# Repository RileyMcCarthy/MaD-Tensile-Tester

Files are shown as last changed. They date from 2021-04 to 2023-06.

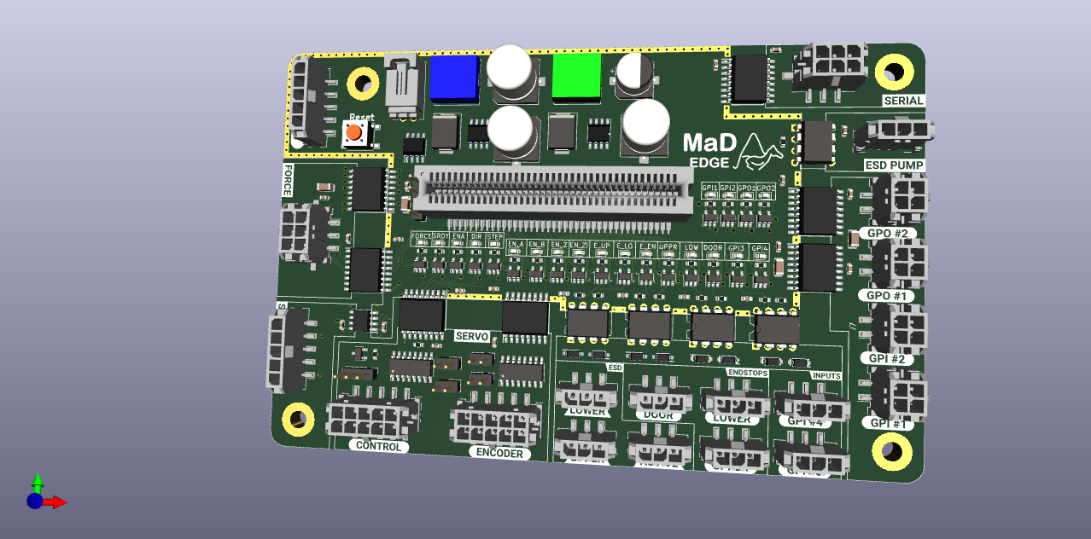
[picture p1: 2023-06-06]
Docs/MaD_Edge_2.png

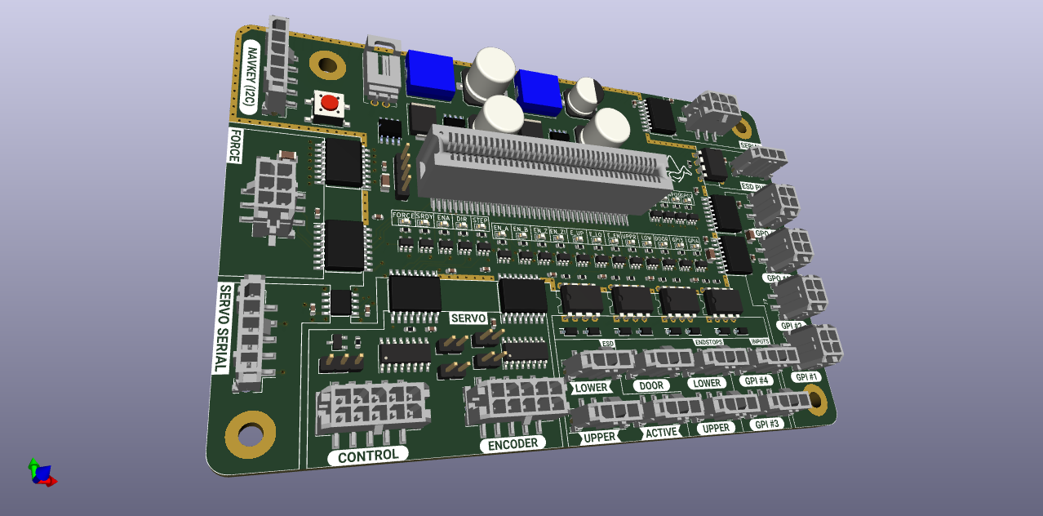
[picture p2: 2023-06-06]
Docs/MaD_Edge_1.png

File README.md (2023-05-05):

# Low Modulus High Speed Tensile Testing Machine

## Purpose

Function as a relatively low cost (< $4,000), portable, spray resistant, user modifiable, open-source uniaxial tensile testing machine for low modulus elastomeric and biologic materials. 

## Physical Specifications

- Strain Rate 0 – 2 m/s

- Force Measurement Range 1 – 10 N

- Gauge Length 10 – 150 mm

- Strain Length 0 – 500 mm

- Data generation rate 1000 sps

## Power Up Sequence

1. Turning on the mains inlet power switch will power the motion control electronics including the “inboard” power on the tensile board 

2. Depressing the on button of the momentary on-off button pair will apply DC power to the machine status switches and ESD chain circuit. 

3. Release of the ESD switch which will apply AC power to the servo controller. 

4. When machine operational and safety criteria are met, motion is affected through operator actuation of the reset function with a control panel and touch screen. 

5. The power down sequence is the reverse of the power up sequence with the off button of the momentary on-off button pair being pressed to remove DC power.

## Operation

The machine state machine operates in three main states with corresponding parameters; 

1. Self Check
- Charge Pump Activated (**ON**/OFF)
2. Machine Check
- Switched Power (**ON**/OFF)
- ESD Travel Limits (**OK**/UPPER FAULT/LOWER FAULT)
- ESD Switch (**ON**/OFF)
- Servo Ready (**YES**/NO)
- Servo Communicating (**YES**/NO)
- Force Gauge Ready (**YES**/NO)
3. Motion
- Mode (Manual or Test)
- Status (DISABLED, ENABLED, SAMPLE LIMIT, MACHINE LIMIT, FAULT)
- Condition (Length, Force, Tension, Compression, Upper Limit, Lower Limit, Door, Stopped, Moving)

## Manual Mode

Manual Operation Mode controls the motor based on user input. The user can selected from the following functions: Off, Incremental Jog, Continuous Jog, Move to Position, Handwheel Jog, Move to Home Position, Set or Move to a Gauge Length, Set or Move to a Force Level and Hold. 

## Test Mode 
Test Mode controls the motor automatically using the functions: Load, Run, Stop Test (Stop Tst) and Hold/Resume.  Motion Profiles are executed by the Run Function. 

** Documentation is a WIP **

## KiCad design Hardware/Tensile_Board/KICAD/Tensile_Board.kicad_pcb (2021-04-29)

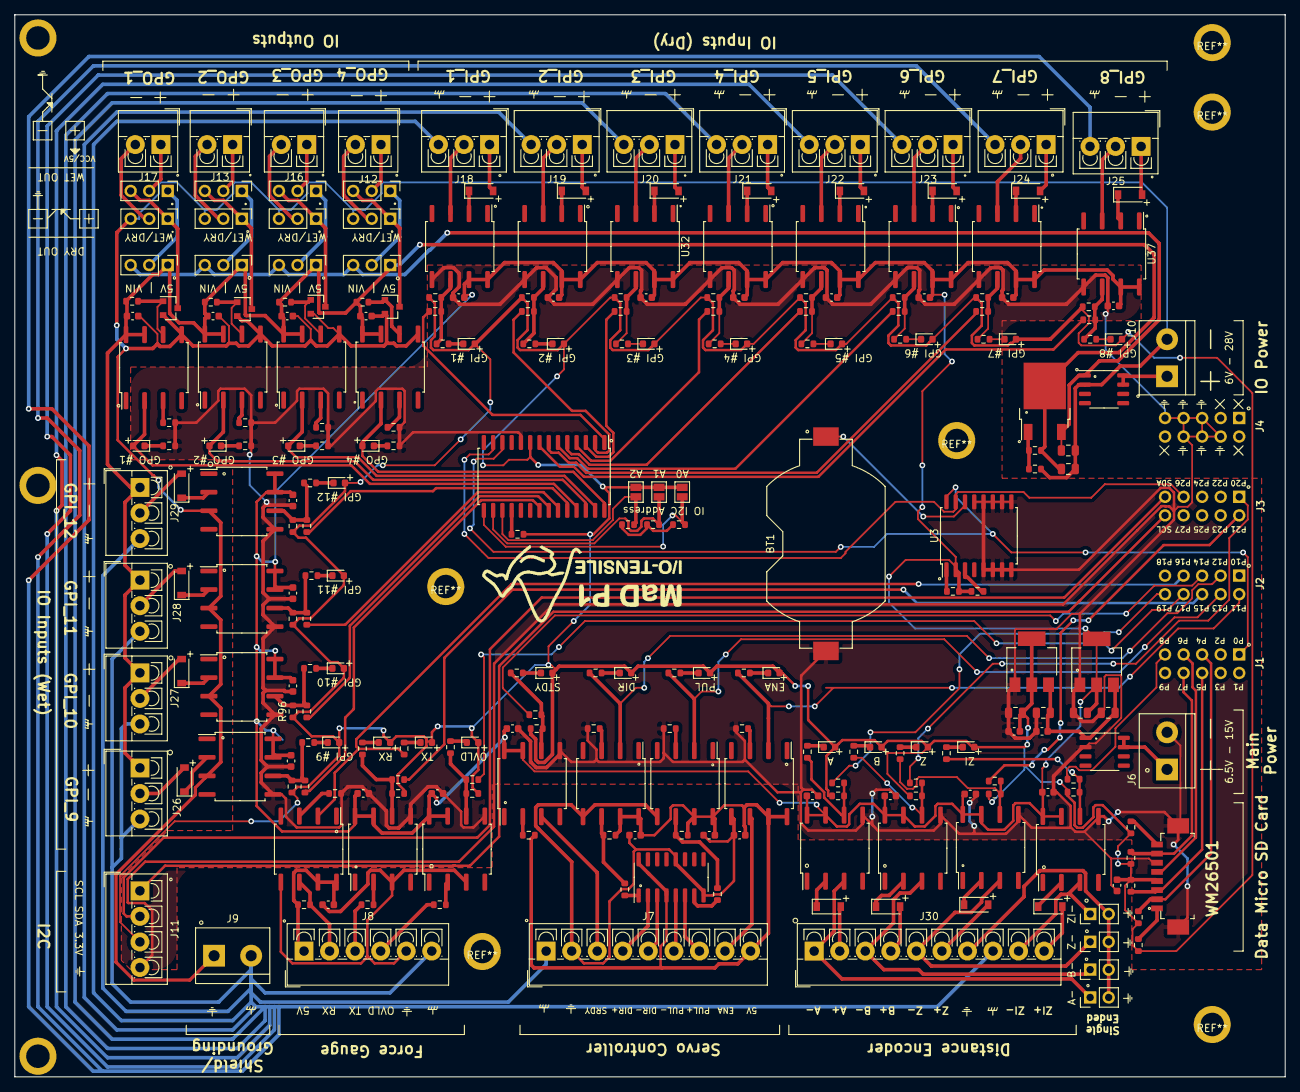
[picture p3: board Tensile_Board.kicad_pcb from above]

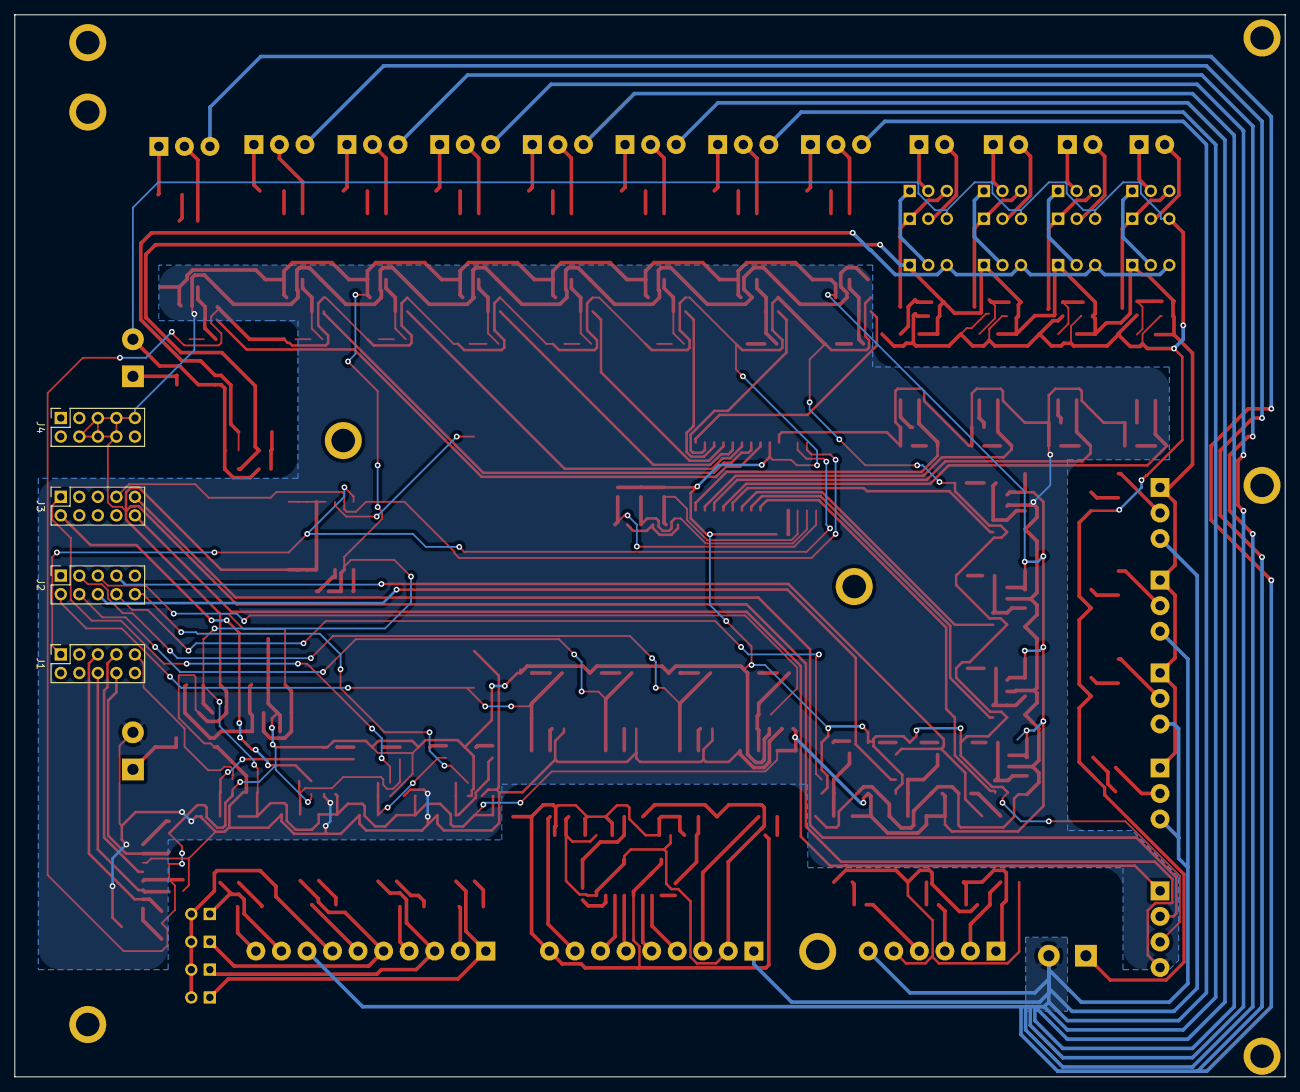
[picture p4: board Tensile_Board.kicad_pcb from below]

Board: 2 copper layers, 174.0 x 145.5 mm, 268 parts (4 on the bottom side), 195 nets.

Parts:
BT1: CR2032; BatteryHolder_Keystone_1058_1x2032
C1, C8, C9, C12, C13, C14, C15, C16, C17, C18, C19, C20, C23, C24, C25, C26, C27, C28, C29, C30, C31, C32, C33, C34, C35, C36, C37, C38: 0.1uF; C_0603_1608Metric
C2, C3: 10uF; C_0805_2012Metric
C4, C6: 4.7uF; C_0805_2012Metric
C5, C7: 1uF; C_0603_1608Metric
C21: 0.1uF; C_0805_2012Metric
C22: 1uF; C_0805_2012Metric
D1, D2, D4, D5, D6, D7, D8, D9, D10, D11, D12, D13, D14, D15, D16, D17, D18, D19, D20, D21, D22, D23, D24, D25, D26, D27: BLUE; LED_0603_1608Metric
D3: LED; LED_0603_1608Metric
DISP_HOLE_1, DISP_HOLE_2, DISP_HOLE_3: Hole_5.08
J1, J2, J3, J4: Conn_02x05_Odd_Even; PinSocket_2x05_P2.54mm_Vertical
J5: Micro_SD_Card; WM26501
J6: Main_Power; TerminalBlock_bornier-2_P5.08mm
J7: Screw_Terminal_01x09; TerminalBlock_4Ucon_1x09_P3.50mm_Vertical
J8: Screw_Terminal_01x06; TerminalBlock_4Ucon_1x06_P3.50mm_Vertical
J9: Grounding; TerminalBlock_bornier-2_P5.08mm
J10: IO_Power; TerminalBlock_bornier-2_P5.08mm
J11: Screw_Terminal_01x04; TerminalBlock_4Ucon_1x04_P3.50mm_Vertical
J12, J13, J16, J17: Screw_Terminal_01x02; TerminalBlock_4Ucon_1x02_P3.50mm_Vertical
J18, J19, J20, J21, J22, J23, J24, J25, J26, J27, J28, J29: Screw_Terminal_01x03; TerminalBlock_4Ucon_1x03_P3.50mm_Vertical
J30: Screw_Terminal_01x10; TerminalBlock_4Ucon_1x10_P3.50mm_Vertical
JP1: A2; SolderJumper-2_P1.3mm_Open_Pad1.0x1.5mm
JP2: A1; SolderJumper-2_P1.3mm_Open_Pad1.0x1.5mm
JP3: A0; SolderJumper-2_P1.3mm_Open_Pad1.0x1.5mm
JP4, JP5, JP6, JP7: Jumper_2_Open; PinHeader_1x02_P2.54mm_Vertical
JP10, JP11, JP12, JP13, JP15, JP16, JP18, JP19, JP21, JP22, JP24, JP25: Jumper_3_Open; PinHeader_1x03_P2.54mm_Vertical
LOGO: LOGO_1
Q3, Q4, Q5, Q6, Q7, Q8, Q9, Q10, Q11, Q12, Q13, Q14, Q15, Q16, Q17, Q18: NSI50010Y; D_SOD-123
R1, R2, R3, R4, R5: 100K; R_0603_1608Metric
R6, R7: 4.7K; R_0603_1608Metric
R8, R9, R17, R24, R25, R26, R27, R28, R29, R38, R39, R40, R41, R56, R57, R58, R59, R60, R61, R68, R69, R70, R71, R72, R73: 10K; R_0603_1608Metric
R10, R11, R18: 360R; R_0603_1608Metric
R12, R19, R20: 470R; R_0603_1608Metric
R13, R14, R15, R21, R42, R43, R44, R45: 270R; R_0603_1608Metric
R16, R32, R33, R34, R35: 620R; R_0603_1608Metric
R22, R23: 330R; R_0603_1608Metric
R30, R31, R36, R37, R50, R51, R52, R53, R54, R55, R62, R63, R64, R65, R66, R67, R77, R78, R79, R80, R81, R82, R83, R84, R85, R86: 100R; R_0603_1608Metric
R46, R47, R48, R49, R87, R88, R89, R90, R91, R92, R93, R94, R95, R96, R97, R98: 1K; R_0603_1608Metric
R74: 680R; R_0603_1608Metric
R75: 220R; R_0603_1608Metric
R76: 33R; R_0603_1608Metric
U1: AMS1117-5.0; SOT-223-3_TabPin2
U2: AMS1117-3.3; SOT-223-3_TabPin2
U3: DS3231M; SOIC-16W_7.5x10.3mm_P1.27mm
U4: AM26LS31CDR; SOIC-16_3.9x9.9mm_P1.27mm
U5, U6, U7, U8, U9, U10, U11, U15, U16, U17, U18, U22, U23, U24, U25, U30, U31, U32, U33, U34, U35, U36, U37, U38, U39, U40, U41: 6N137; SOP-8_6.62x9.15mm_P2.54mm
U12: MCP23017_SO; SOIC-28W_7.5x17.9mm_P1.27mm
U13, U20: APM4953; SOP-8_3.9x4.9mm_P1.27mm
U21: LM317_TO-252; TO-252-2
U26, U27, U28, U29: NUD3124; SOT-23

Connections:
5V_IO: C22.1, C23.1, C24.1, C25.1, C26.1, J26.1, J27.1, J28.1, J29.1, JP10.1, JP11.1, JP12.1, JP13.1, R46.1, R47.1, R48.1, R49.1, R75.1, U21.2, U22.7, U22.8, U23.7, U23.8, U24.7, U24.8, U25.7, U25.8
+3V3_TS: C1.1, C6.1, C7.1, D1.2, D2.2, D7.2, D8.2, D9.2, D10.2, D11.2, D12.2, D13.2, D14.2, D15.2, D16.2, D17.2, D18.2, D19.2, D20.2, D21.2, D22.2, D23.2, D24.2, D25.2, D26.2, D27.2, J5.4, J11.3, JP1.1, JP2.1, JP3.1, R1.1, R2.1, R3.1, R4.1, R5.1, R16.1, R22.1, R23.1, R28.1, R32.1, R33.1, R34.1, R35.1, R87.1, R88.1, R89.1, R90.1, R91.1, R92.1, R93.1, R94.1, R95.1, R96.1, R97.1, R98.1, U2.2, U12.9
+5V_FG: C18.1, J8.1, R18.1, U9.7, U9.8
+5V_SC: C8.1, C9.1, C16.1, J7.9, R10.1, R11.1, R12.1, U4.4, U4.16, U5.7, U5.8, U6.7, U6.8, U7.7, U7.8
+5V_TS: C3.1, C12.1, C13.1, C14.1, C15.1, C17.1, C19.1, C20.1, C27.1, C28.1, C29.1, C30.1, C31.1, C32.1, C33.1, C34.1, C35.1, C36.1, C37.1, C38.1, R6.1, R7.1, U1.2, U3.2, U8.7, U8.8, U10.7, U10.8, U11.7, U11.8, U15.7, U15.8, U16.7, U16.8, U17.7, U17.8, U18.7, U18.8, U30.7, U30.8, U31.7, U31.8, U32.7, U32.8, U33.7, U33.8, U34.7, U34.8, U35.7, U35.8, U36.7, U36.8, U37.7, U37.8, U38.7, U38.8, U39.7, U39.8, U40.7, U40.8, U41.7, U41.8
DIR: R8.1, U4.1
DIR+: J7.4, U4.2
DIR-: J7.5, U4.3
ENA: J7.8, U6.6
FG_OVLD: J8.4, R19.1
FG_RX: J8.2, R18.2, U9.6
FG_TX: J8.3, R20.1
GND: R26.2, R27.2, R29.2
GND_ENC: J30.7, JP4.2, JP5.2, JP6.2, JP7.2
GND_FG: C18.2, J8.5, U9.5, U10.3, U11.3
GND_IO: C21.2, C22.2, C23.2, C24.2, C25.2, C26.2, J9.1, J10.2, JP16.3, JP19.3, JP22.3, JP25.3, R74.2, U13.2, U22.5, U23.5, U24.5, U25.5, U26.2, U27.2, U28.2, U29.2, U38.3, U39.3, U40.3, U41.3
GND_SC: C8.2, C9.2, C16.2, J7.2, U4.8, U4.12, U5.5, U6.5, U7.5
GND_TSD: BT1.2, C1.2, C2.2, C3.2, C4.2, C5.2, C6.2, C7.2, C12.2, C13.2, C14.2, C15.2, C17.2, C19.2, C20.2, C27.2, C28.2, C29.2, C30.2, C31.2, C32.2, C33.2, C34.2, C35.2, C36.2, C37.2, C38.2, J4.4, J4.5, J4.6, J4.7, J4.8, J4.9, J5.6, J5.9, J6.2, J11.4, R13.2, R14.2, R15.2, R21.2, R42.2, R43.2, R44.2, R45.2, R76.2, R77.2, R78.2, R79.2, U1.1, U2.1, U3.5, U3.6, U3.7, U3.8, U3.9, U3.10, U3.11, U3.12, U3.13, U8.5, U10.5, U11.5, U12.10, U15.5, U16.5, U17.5, U18.5, U20.2, U30.5, U31.5, U32.5, U33.5, U34.5, U35.5, U36.5, U37.5, U38.5, U39.5, U40.5, U41.5
GPA0: R70.1, U12.21
GPA1: R71.1, U12.22
GPA2: R72.1, U12.23
GPA3: R73.1, U12.24
GPA4: D6.2, U12.25, U25.2
GPA5: D4.2, U12.26, U23.2
GPA6: D5.2, U12.27, U24.2
GPA7: D3.2, U12.28, U22.2
GPB0: R56.1, U12.1
GPB1: R57.1, U12.2
GPB2: R58.1, U12.3
GPB3: R59.1, U12.4
GPB4: R60.1, U12.5
GPB5: R61.1, U12.6
GPB6: R68.1, U12.7
GPB7: R69.1, U12.8
GPI_1+: J18.1, Q7.2
GPI_1-: J18.2, U30.3
GPI_2+: J19.1, Q8.2
GPI_2-: J19.2, U31.3
GPI_3+: J20.1, Q9.2
GPI_3-: J20.2, U32.3
GPI_4+: J21.1, Q10.2
GPI_4-: J21.2, U33.3
GPI_5+: J22.1, Q11.2
GPI_5-: J22.2, U34.3
GPI_6+: J23.1, Q12.2
GPI_6-: J23.2, U35.3
GPI_7+: J24.1, Q13.2
GPI_7-: J24.2, U36.3
GPI_8+: J25.1, Q14.2
GPI_8-: J25.2, U37.3
GPI_9: J26.2, Q15.2
GPI_10: J27.2, Q16.2
GPI_11: J28.2, Q17.2
GPI_12: J29.2, Q18.2
GPO_1+: J17.1, JP24.2
GPO_1-: J17.2, JP25.2
GPO_2+: J13.1, JP18.2
GPO_2-: J13.2, JP19.2
GPO_3+: J16.1, JP21.2
GPO_3-: J16.2, JP22.2
GPO_4+: J12.1, JP15.2
GPO_4-: J12.2, JP16.2
GPO_D1: JP24.3, JP25.1, U29.3
GPO_D2: JP18.3, JP19.1, U27.3
GPO_D3: JP21.3, JP22.1, U28.3
GPO_D4: JP15.3, JP16.1, U26.3
unnamed: BT1.1, U3.14
unnamed: D1.1, R50.1
unnamed: D2.1, R30.1
unnamed: D3.1, R76.1
unnamed: D4.1, R77.1
unnamed: D5.1, R78.1
unnamed: D6.1, R79.1
unnamed: D7.1, R51.1
unnamed: D8.1, R52.1
unnamed: D9.1, R53.1
unnamed: D10.1, R54.1
unnamed: D11.1, R55.1
unnamed: D12.1, R62.1
unnamed: D13.1, R63.1
unnamed: D14.1, R64.1
unnamed: D15.1, R65.1
unnamed: D16.1, R66.1
unnamed: D17.1, R67.1
unnamed: D18.1, R31.1
unnamed: D19.1, R36.1
unnamed: D20.1, R37.1
unnamed: D21.1, R80.1
unnamed: D22.1, R81.1
unnamed: D23.1, R82.1
unnamed: D24.1, R83.1
unnamed: D25.1, R84.1
unnamed: D26.1, R85.1
unnamed: D27.1, R86.1
unnamed: J5.1, R5.2
unnamed: J5.8, R1.2
unnamed: J6.1, U20.7, U20.8
unnamed: J10.1, U13.7, U13.8
unnamed: JP1.2, R26.1, U12.17
unnamed: JP2.2, R27.1, U12.16
unnamed: JP3.2, R29.1, U12.15
unnamed: Q3.1, U15.2
unnamed: Q4.1, U16.2
unnamed: Q5.1, U17.2
unnamed: Q6.1, U18.2
unnamed: Q7.1, U30.2
unnamed: Q8.1, U31.2
unnamed: Q9.1, U32.2
unnamed: Q10.1, U33.2
unnamed: Q11.1, U34.2
unnamed: Q12.1, U35.2
unnamed: Q13.1, U36.2
unnamed: Q14.1, U37.2
unnamed: Q15.1, U38.2
unnamed: Q16.1, U39.2
unnamed: Q17.1, U40.2
unnamed: Q18.1, U41.2
unnamed: R6.2, U3.1
unnamed: R7.2, U3.3
unnamed: R8.2, R10.2, U5.6
unnamed: R9.2, R11.2, U7.6
unnamed: R12.2, U8.2
unnamed: R13.1, U5.3
unnamed: R14.1, U6.3
unnamed: R15.1, U7.3
unnamed: R16.2, R17.2, R37.2, U8.6
unnamed: R19.2, U10.2
unnamed: R20.2, U11.2
unnamed: R21.1, U9.3
unnamed: R22.2, R24.2, R81.2, U10.6
unnamed: R23.2, R25.2, R82.2, U11.6
unnamed: R28.2, U12.18
unnamed: R32.2, R38.2, R86.2, U15.6
unnamed: R33.2, R39.2, R85.2, U16.6
unnamed: R34.2, R40.2, R84.2, U17.6
unnamed: R35.2, R41.2, R83.2, U18.6
unnamed: R42.1, U22.3
unnamed: R43.1, U23.3
unnamed: R44.1, U24.3
unnamed: R45.1, U25.3
unnamed: R46.2, U22.6, U26.1
unnamed: R47.2, U23.6, U27.1
unnamed: R48.2, U24.6, U28.1
unnamed: R49.2, U25.6, U29.1
unnamed: R50.2, R56.2, R87.2, U30.6
unnamed: R51.2, R57.2, R88.2, U31.6
unnamed: R52.2, R58.2, R89.2, U32.6
unnamed: R53.2, R59.2, R90.2, U33.6
unnamed: R54.2, R60.2, R91.2, U34.6
unnamed: R55.2, R61.2, R92.2, U35.6
unnamed: R62.2, R68.2, R93.2, U36.6
unnamed: R63.2, R69.2, R94.2, U37.6
unnamed: R64.2, R70.2, R95.2, U38.6
unnamed: R65.2, R71.2, R96.2, U39.6
unnamed: R66.2, R72.2, R97.2, U40.6
unnamed: R67.2, R73.2, R98.2, U41.6
unnamed: R74.1, R75.2, U21.1
OUTA+: J30.2, Q6.2
OUTA-: J30.1, JP7.1, U18.3
OUTB+: J30.4, Q5.2
OUTB-: J30.3, JP6.1, U17.3
OUTZ+: J30.6, Q4.2
OUTZ-: J30.5, JP5.1, U16.3
OUTZI+: J30.10, Q3.2
OUTZI-: J30.9, JP4.1, U15.3
P0: J1.1, U3.16, U12.12
P4: J1.5, J5.2, R4.2
P5: J1.6, J5.3, R3.2
P6: J1.7, J5.5
P7: J1.8, J5.7, R2.2
P8: J1.9, R38.1
P11: J2.2, R31.2, U6.2
P12: J2.3, R30.2, U5.2
P13: J2.4, R36.2, U7.2
P14: J2.5, R17.1
P15: J2.6, R25.1
P16: J2.7, R80.2, U9.2
P17: J2.8, R24.1
P19: J2.10, R41.1
P20: J3.1, R40.1
P21: J3.2, R39.1
P26: J3.7, U3.15, U12.13
PUL: R9.1, U4.7
PUL+: J7.7, U4.6
PUL-: J7.6, U4.5
SCL: J3.10, J11.1
SDA: J3.9, J11.2
SHIELD: J7.1, J8.6, J9.2, J18.3, J19.3, J20.3, J21.3, J22.3, J23.3, J24.3, J25.3, J26.3, J27.3, J28.3, J29.3, J30.8
SRDY: J7.3, U8.3
VIN_IO: C21.1, JP10.3, JP11.3, JP12.3, JP13.3, U13.1, U21.3
V_GPO1: JP13.2, JP24.1
V_GPO2: JP11.2, JP18.1
V_GPO3: JP12.2, JP21.1
V_GPO4: JP10.2, JP15.1
V_IN: C2.1, C4.1, C5.1, U1.3, U2.3, U20.1

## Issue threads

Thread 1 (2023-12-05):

NavKey Jogging - Jog Increment Size Resolution

oldnslow, 2023-12-05:
**Function Change**
- add 0.1 mm jog increment

**Rationale**
- resolution required to set gauge length / preload force, particularly for short test samples

**Priority**
- medium

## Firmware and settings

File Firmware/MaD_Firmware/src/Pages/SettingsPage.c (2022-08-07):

#include "SettingsPage.h"
#include <stdlib.h>

#define BUTTONCOUNT 23
#define BUTTON_NAVIGATION 0
#define BUTTON_NAME 1
#define BUTTON_NUMBER 2
#define BUTTON_CONFIGURATION_MOTORTYPE 3
#define BUTTON_CONFIGURATION_MAXMOTORTORQUE 4
#define BUTTON_CONFIGURATION_MAXMOTORRPM 5
#define BUTTON_CONFIGURATION_GEARDIAMETER 6
#define BUTTON_CONFIGURATION_GEARPITCH 7
#define BUTTON_CONFIGURATION_SYSTEMINTERTIA 8
#define BUTTON_CONFIGURATION_STATICTORQUE 9
#define BUTTON_CONFIGURATION_LOAD 10
#define BUTTON_CONFIGURATION_POSITIONENCODERTYPE 11
#define BUTTON_CONFIGURATION_POSITIONENCODERSCALEFACTOR 12
#define BUTTON_CONFIGURATION_FORCEGAUGE 13
#define BUTTON_CONFIGURATION_FORCEGAUGESCALEFACTOR 14
#define BUTTON_CONFIGURATION_FORCEGAUGENEUTRALOFFSET 15
#define BUTTON_PERFORMANCE_MINPOSITION 16
#define BUTTON_PERFORMANCE_MAXPOSITION 17
#define BUTTON_PERFORMANCE_MAXVELOCITY 18
#define BUTTON_PERFORMANCE_MAXACCELERATION 19
#define BUTTON_PERFORMANCE_MAXFORCETENSILE 20
#define BUTTON_PERFORMANCE_MAXFORCECOMPRESSION 21
#define BUTTON_PERFORMANCE_FORCEGAUGENEUTRALOFFSET 22

static bool complete;

static bool isNumber(char *string)
{
    int i = 0;
    while (string[i] != '\0')
    {
        if (!isdigit(string[i]) && string[i] != '-')
        {
            return false;
        }
        i++;
    }
    return true;
}

static bool isDouble(char *string)
{
    int i = 0;
    while (string[i] != '\0')
    {
        if (!isdigit(string[i]) && string[i] != '.' && string[i] != '-')
        {
            return false;
        }
        i++;
    }
    return true;
}

static bool setting_button(int id, void *arg)
{
    SettingsPage *page = (SettingsPage *)arg;
    Keyboard *keyboard = keyboard_create(page->display, page->images);
    switch (id)
    {
    case BUTTON_NAVIGATION:
        complete = true;
        break;
    case BUTTON_NAME:
    {
        char *name = keyboard_get_input(keyboard, "Name: ");
        if (name != NULL && strlen(name) > 0)
        {
            strcpy(page->machineProfile->name, name);
        }
        break;
    }
    case BUTTON_NUMBER:
    {
        char *number = keyboard_get_input(keyboard, "Number: ");
        if (number != NULL && isNumber(number))
        {
            page->machineProfile->number = atoi(number);
        }
        break;
    }
    case BUTTON_CONFIGURATION_MOTORTYPE:
    {
        char *type = keyboard_get_input(keyboard, "Motor Type: ");
        if (type != NULL && strlen(type) > 0)
        {
            strcpy(page->machineProfile->configuration.motorType, type);
        }
        break;
    }
    case BUTTON_CONFIGURATION_MAXMOTORTORQUE:
    {
        char *torque = keyboard_get_input(keyboard, "Max Torque: ");
        if (torque != NULL && isDouble(torque))
        {
            page->machineProfile->configuration.maxMotorTorque = atof(torque);
        }
        break;
    }
    case BUTTON_CONFIGURATION_MAXMOTORRPM:
    {
        char *rpm = keyboard_get_input(keyboard, "Max RPM: ");
        if (rpm != NULL && isDouble(rpm))
        {
            page->machineProfile->configuration.maxMotorRPM = atof(rpm);
        }
        break;
    }
    case BUTTON_CONFIGURATION_GEARDIAMETER:
    {
        char *diameter = keyboard_get_input(keyboard, "Gear Diameter: ");
        if (diameter != NULL && isDouble(diameter))
        {
            page->machineProfile->configuration.gearDiameter = atof(diameter);
        }
        break;
    }
    case BUTTON_CONFIGURATION_GEARPITCH:
    {
        char *pitch = keyboard_get_input(keyboard, "Gear Pitch: ");
        if (pitch != NULL && isDouble(pitch))
        {
            page->machineProfile->configuration.gearPitch = atof(pitch);
        }
        break;
    }
    case BUTTON_CONFIGURATION_SYSTEMINTERTIA:
    {
        char *inertia = keyboard_get_input(keyboard, "Inertia: ");
        if (inertia != NULL && isDouble(inertia))
        {
            page->machineProfile->configuration.systemIntertia = atof(inertia);
        }
        break;
    }
    case BUTTON_CONFIGURATION_STATICTORQUE:
    {
        char *torque = keyboard_get_input(keyboard, "Static Torque: ");
        if (torque != NULL && isDouble(torque))
        {
            page->machineProfile->configuration.staticTorque = atof(torque);
        }
        break;
    }
    case BUTTON_CONFIGURATION_LOAD:
    {
        char *load = keyboard_get_input(keyboard, "Load: ");
        if (load != NULL && isDouble(load))
        {
            page->machineProfile->configuration.load = atof(load);
        }
        break;
    }
    case BUTTON_CONFIGURATION_POSITIONENCODERTYPE:
    {
        char *encoder = keyboard_get_input(keyboard, "Encoder Type: ");
        if (encoder != NULL && strlen(encoder) > 0)
        {
            strcpy(page->machineProfile->configuration.positionEncoderType, encoder);
        }
        break;
    }
    case BUTTON_CONFIGURATION_POSITIONENCODERSCALEFACTOR:
    {
        char *scale = keyboard_get_input(keyboard, "Encoder Slope: ");
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

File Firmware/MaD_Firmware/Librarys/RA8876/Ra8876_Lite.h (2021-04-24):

//**************************************************************//
/*
File Name : Ra8876_Lite.h                                   
Author    : RAiO Application Team, Modified by Riley McCarthy                           
Edit Date : 09/13/2017
Version   : v1.0
*/
//**************************************************************//

#ifndef Ra8876_Lite_H
#define Ra8876_Lite_H

typedef signed char rs8;
typedef signed short rs16;
typedef signed long rs32;
typedef unsigned char ru8;
typedef unsigned short ru16;
typedef unsigned long ru32;

#include "simpletools.h"
#include "SPI_Fast.h"
#include "libpropeller/sd/sd.h"
#include "Error.h"

#define RA8876_SPI_CMDWRITE 0x00
#define RA8876_SPI_DATAWRITE 0x80
#define RA8876_SPI_DATAREAD 0xc0
#define RA8876_SPI_STATUSREAD 0x40

/*==== [SW_(1)]  PLL  =====*/
//Crystal resonator for RA8876, suggested 10MHz
//SDRAMaccess clock,suggested 50~160MHz
//RA8876 system core clock, suggested 50~130MHz
//TFTdriving clock PCLK,refer to LCD SPEC specified PCLK frequency requirements
//DRAM_FREQ>= CORE_FREQ
//CORE_FREQ>= 2 * SCAN_FREQ

#define OSC_FREQ 10   // OSC clock frequency, unit: MHz.
#define DRAM_FREQ 120 // SDRAM clock frequency, unit: MHz.
#define CORE_FREQ 120 // Core (system) clock frequency, unit: MHz.
#define SCAN_FREQ 50  // Panel Scan clock frequency, unit: MHz.

#define W9812G6JH

/*TFT timing configure*/
#define TFT_MODE 0   //0:SYNC_mode(SYNC+DE mode), 1: DE mode  //if sync only mode do not connect DE signal or XDE_INV = 1
#define XHSYNC_INV 1 // 0:no inversion, 1:inversion
#define XVSYNC_INV 1 // 0:no inversion, 1:inversion
#define XDE_INV 0    // 0:no inversion, 1:inversion
#define XPCLK_INV 1  // 0:no inversion, 1:inversion
#define HPW 70       //
#define HND 160
#define HDW 1024
#define HST 160
#define VPW 10
#define VND 23
#define VDH 600
#define VST 12

#define RA8877_LVDS_FORMAT 0 // 0:Format1(VESA format), 1:Format2 =(JEIDA format)

#define SCREEN_WIDTH 1024
#define SCREEN_HEIGHT 600

/*Page(image buffer) configure*/
/*The maximum number of pages is based on SDRAM capacity and color depth and width and height of one page*/
/*For example we used W9825G6JH SDRAM that capacity =  32Mbyte */
/*The SDRAM is divided into several image buffers and the maximum number of image buffers is limited by the 
memory size. For example : page_size = 1024*600*2byte(16bpp) = 1228800byte, maximum number = 16/1.2288 */
/*vertical mulit page application*/
#define PAGE1_START_ADDR 0
#define PAGE2_START_ADDR 1024 * 600 * 2
#define PAGE3_START_ADDR 1024 * 600 * 2 * 2
#define PAGE4_START_ADDR 1024 * 600 * 2 * 3
#define PAGE5_START_ADDR 1024 * 600 * 2 * 4
#define PAGE6_START_ADDR 1024 * 600 * 2 * 5
#define PAGE7_START_ADDR 1024 * 600 * 2 * 6
#define PAGE8_START_ADDR 1024 * 600 * 2 * 7
#define PAGE9_START_ADDR 1024 * 600 * 2 * 8
#define PAGE10_START_ADDR 1024 * 600 * 2 * 9

#define PATTERN1_RAM_START_ADDR 1024 * 600 * 2 * 10
#define PATTERN2_RAM_START_ADDR (1024 * 600 * 2 * 10) + (16 * 16 * 2)
#define PATTERN3_RAM_START_ADDR (1024 * 600 * 2 * 10) + (16 * 16 * 2) + (16 * 16 * 2)

/*DMA picture data start address*/
#define WP1_ADDR 0
#define WP2_ADDR 1024 * 600 * 2
#define WP3_ADDR 1024 * 600 * 2 * 2
#define WP4_ADDR 1024 * 600 * 2 * 3
#define WP5_ADDR 1024 * 600 * 2 * 4
#define WP6_ADDR 1024 * 600 * 2 * 5

#define COLOR65K_BLACK 0x0000
#define COLOR65K_WHITE 0xffff
#define COLOR65K_RED 0xf800
#define COLOR65K_LIGHTRED 0xfc10
#define COLOR65K_DARKRED 0x8000
#define COLOR65K_GREEN 0x07e0
#define COLOR65K_LIGHTGREEN 0x87f0
#define COLOR65K_DARKGREEN 0x0400
#define COLOR65K_BLUE 0x001f
#define COLOR65K_BLUE2 0x051f
#define COLOR65K_LIGHTBLUE 0x841f
#define COLOR65K_DARKBLUE 0x0010
#define COLOR65K_YELLOW 0xffe0
#define COLOR65K_LIGHTYELLOW 0xfff0
#define COLOR65K_DARKYELLOW 0x8400
#define COLOR65K_CYAN 0x07ff
#define COLOR65K_LIGHTCYAN 0x87ff
#define COLOR65K_DARKCYAN 0x0410
#define COLOR65K_MAGENTA 0xf81f
#define COLOR65K_LIGHTMAGENTA 0xfc1f
#define COLOR65K_DARKMAGENTA 0x8010
#define COLOR65K_BROWN 0xA145

#define COLOR65K_GRAYSCALE1 2113
#define COLOR65K_GRAYSCALE2 2113 * 2
#define COLOR65K_GRAYSCALE3 2113 * 3
#define COLOR65K_GRAYSCALE4 2113 * 4
#define COLOR65K_GRAYSCALE5 2113 * 5
#define COLOR65K_GRAYSCALE6 2113 * 6
#define COLOR65K_GRAYSCALE7 2113 * 7
#define COLOR65K_GRAYSCALE8 2113 * 8
#define COLOR65K_GRAYSCALE9 2113 * 9
#define COLOR65K_GRAYSCALE10 2113 * 10
#define COLOR65K_GRAYSCALE11 2113 * 11
#define COLOR65K_GRAYSCALE12 2113 * 12
#define COLOR65K_GRAYSCALE13 2113 * 13
#define COLOR65K_GRAYSCALE14 2113 * 14
#define COLOR65K_GRAYSCALE15 2113 * 15
#define COLOR65K_GRAYSCALE16 2113 * 16
#define COLOR65K_GRAYSCALE17 2113 * 17
#define COLOR65K_GRAYSCALE18 2113 * 18
#define COLOR65K_GRAYSCALE19 2113 * 19
#define COLOR65K_GRAYSCALE20 2113 * 20
#define COLOR65K_GRAYSCALE21 2113 * 21
#define COLOR65K_GRAYSCALE22 2113 * 22
#define COLOR65K_GRAYSCALE23 2113 * 23
#define COLOR65K_GRAYSCALE24 2113 * 24
#define COLOR65K_GRAYSCALE25 2113 * 25
#define COLOR65K_GRAYSCALE26 2113 * 26
#define COLOR65K_GRAYSCALE27 2113 * 27
#define COLOR65K_GRAYSCALE28 2113 * 28
#define COLOR65K_GRAYSCALE29 2113 * 29
#define COLOR65K_GRAYSCALE30 2113 * 30

#define STRING_LINE1 0
#define STRING_LINE2 32
#define STRING_LINE3 32 * 2
#define STRING_LINE4 32 * 3
#define STRING_LINE5 32 * 4
#define STRING_LINE6 32 * 5
#define STRING_LINE7 32 * 6
#define STRING_LINE8 32 * 7
#define STRING_LINE9 32 * 8
#define STRING_LINE10 32 * 9
#define STRING_LINE11 32 * 10
#define STRING_LINE12 32 * 11
#define STRING_LINE13 32 * 12
#define STRING_LINE14 32 * 13
#define STRING_LINE15 32 * 14
#define STRING_LINE16 32 * 15
#define STRING_LINE17 32 * 16
#define STRING_LINE18 32 * 17
#define STRING_LINE19 32 * 18

/*RA8876,8877 register & bit*/
#define RA8876_SRR 0x00
#define RA8876_SOFTWARE_RESET 0xD7

#define RA8876_CCR 0x01
#define RA8876_PLL_DISABLE 0
#define RA8876_PLL_ENABLE 1
#define RA8876_WAIT_NO_MASK 0
#define RA8876_WAIT_MASK 1
#define RA8876_KEY_SCAN_DISABLE 0
#define RA8876_KEY_SCAN_ENABLE 1
#define RA8876_TFT_OUTPUT24 0
#define RA8876_TFT_OUTPUT18 1
#define RA8876_TFT_OUTPUT16 3
#define RA8876_I2C_MASTER_DISABLE 0
#define RA8876_I2C_MASTER_ENABLE 1
#define RA8876_SERIAL_IF_DISABLE 0
#define RA8876_SERIAL_IF_ENABLE 1
#define RA8876_HOST_DATA_BUS_8BIT 0
#define RA8876_HOST_DATA_BUS_SERIAL 0
#define RA8876_HOST_DATA_BUS_16BIT 1

#define RA8876_MACR 0x02
#define RA8876_DIRECT_WRITE 0             // (for all 8 bits MPU I/F, 16 bits MPU I/F with 8bpp data mode 1 & 2, 16 bits MPU I/F with 16/24-bpp data mode 1 & serial host interface)
#define RA8876_MASK_HIGH_BYTE 2           // (ex. 16 bit MPU I/F with 8-bpp data mode 1)
#define RA8876_MASK_HIGH_BYTE_EVEN_DATA 3 //(ex. 16 bit MPU I/F with 24-bpp data mode 2)
#define RA8876_READ_MEMORY_LRTB 0
#define RA8876_READ_MEMORY_RLTB 1
#define RA8876_READ_MEMORY_TBLR 2
#define RA8876_READ_MEMORY_BTLR 3
#define RA8876_WRITE_MEMORY_LRTB 0
#define RA8876_WRITE_MEMORY_RLTB 1
#define RA8876_WRITE_MEMORY_TBLR 2
#define RA8876_WRITE_MEMORY_BTLR 3
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

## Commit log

2021-04-02 init commit
    [DS2_Addon-B_Cu.gbr, DS2_Addon-B_Mask.gbr, DS2_Addon-B_Paste.gbr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]
2021-04-17 Merging all tensile testing machine related repositorys into a single repo
    [Distance_Gauge.sch, Force_Gauge.sch, IO.xlsx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]
2021-04-24 Updated MaD_Firmware with demo code, issues with stack overflow will be updating soon
    [Tensile_Board.sch]
2021-04-24 Updated MaD_Firmware with demo. Current contains stack overflow issues
    [MaD.h, ManualPage.cpp, Ra8876_Lite.h]
2021-04-27 Removed duplicate Tensile Board folder
    [Distance_Gauge.sch, Force_Gauge.sch, IO.xlsx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]
2021-04-29 Fixed polarity issue with Tensile board
    [Tensile_Board.kicad_pcb]
2021-05-03 started changing LDO's to buck regulators
    [Tensile_Board.sch]
2021-05-05 groundwork for p2
    [MAD_Board.sch, MAD_P2.kicad_pcb, MAD_P2.sch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]
2021-05-06 Created power system for the MAD_P2 board, using evaluation board as reference
    [IO Power.sch, MAD_P2.sch, Power.sch]
2021-05-07 Added memory and usb to schematic
    [IO Power.sch, MAD_P2.sch, Memory.sch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]
2021-05-08 Added wifi to board
    [Connections.sch, IO Power.sch, MAD_P2.sch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]
2021-05-10 added adc
    [Connections.sch, MAD_P2.sch, Memory.sch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]
2021-05-10 changed adc to ads131
    [Peripherals.sch, Power2.sch]
2021-05-10 finished adc, added dac
    [Connections.sch, MAD_P2.sch, Memory.sch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]
2021-05-12 began pcb layout
    [Connections.sch, MAD_P2.kicad_pcb, MAD_P2.sch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]
2021-05-13 completed power section of board
    [MAD_P2.kicad_pcb]
2021-05-17 finished board layout
    [Connections.sch, MAD_P2.kicad_pcb, Peripherals.sch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]
2021-05-17 added lcsc part numbers to bom
    [Connections.sch, MAD_P2.sch, Memory.sch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]
2021-05-20 replaced ads131E with ads131A
    [MAD_P2.kicad_pcb, Peripherals.sch, PeripheralsCont.sch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]
2021-05-21 added optional sd card socket for data
    [Connections.sch, MAD_P2.sch, Peripherals.sch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]
2021-05-21 revising pcb layout
    [Connections.sch, MAD_P2.kicad_pcb, MAD_P2.sch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]
2021-05-22 finished power supply board layout
    [MAD_P2.kicad_pcb]
2021-05-22 begining layout of adc/dac
    [MAD_P2.kicad_pcb]
2021-05-23 general layout complete
    [MAD_P2.kicad_pcb]
2021-05-24 routing power section
    [MAD_P2.kicad_pcb]
2021-05-27 routed adc
    [Connections.sch, MAD_P2.kicad_pcb, MAD_P2.sch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]
2021-05-28 finished routing ground plane
    [MAD_P2.kicad_pcb]
2021-06-04 changed to 4 layer board due to number of wires to route. Routed ground and power nets
    [Connections.sch, MAD_P2.kicad_pcb, Power2.sch]
2021-06-05 fixed DAC issue and added silkscreen
    [70553-0001.stp, Connections.sch, MAD_P2.kicad_pcb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]
2021-06-07 pushing updates before big change
    [MAD_P2.kicad_pcb]
2021-06-21 begining autorouter, had to start again after edge connector footprint was incorrect
    [MAD_P2.kicad_pcb]
2021-06-21 added boarders along keep out zones for autorouter:
    [MAD_P2.kicad_pcb]
2021-06-21 added keepout areas to adc/dac
    [MAD_P2.kicad_pcb]
2021-06-21 added silkscreen
    [MAD_P2.kicad_pcb]
2021-06-22 errors with connections to edge module fixed, created new dsn for autorouting
    [MAD_P2.kicad_pcb]
2021-06-22 re-routed power lines to edge module for optimized routes
    [MAD_P2.kicad_pcb]
2021-06-24 backup push before dsn import
    [MAD_P2.kicad_pcb]
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2021-06-29 completed BOM with digikey and LSCS parts
    [Connections.sch, MAD_P2.sch, Memory.sch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]
2021-06-29 Finished re-routing the power and important connections. exported dsn for this stage of routing. running autorouter, may have few more commits before finished route
    [Connections.sch, Power.sch]
2021-07-03 board complete, exporting production files
    [MAD_P2-B_Cu.gbr, MAD_P2-B_Mask.gbr, MAD_P2-B_Paste.gbr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]
2021-07-05 updated bom with lcsc part #
    [Connections.sch, MAD_P2.kicad_pcb, Memory.sch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]
2021-08-06 Big update! All code is converted to the propeller 2 (mostly it compiles, many protocols needs conversion i2c,spi,ect). JSON library has gotten complete overhaul, now Machine Profiles can be transfer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
2021-08-09 added more functionality to JSON for motion quartet, motion set, motion profiles, machine profile, and more
    [Connections.sch, MAD_P2.kicad_pcb, MAD_P2.sch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]
2021-08-12 JSON library has all tests passing using larger heap size of 32768. I also added leak detection library which is not currently enabled in the makefile, next step is to run that
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2021-08-13 memory leak detection working with all JSON tests running and no leaks, can view the amount of bytes currently allocated
2021-09-11 display running properly, touch functionality temporarly not working... either code or EMI from bad header connectio
    [MaD.h]
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2022-01-24 syncing info
    [Distance_Gauge.kicad_sch, Force_Gauge.kicad_sch, IO_Expansion.kicad_sch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]
2022-04-06 big update
    [DesignProject.kicad_pcb, DesignProject.kicad_sch, diff.txt]
2022-05-04 fixed file reading and writing
    [SettingsPage.c]
2022-07-14 backing up before upddate
    [diff.txt]
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2022-12-22 moving web to /Software
    [effect_sizes23.xlsx]
2023-03-23 Large update
    [test_data.csv]
2023-04-28 cleaning up repo
    [test_data.csv]
2023-04-28 more files to clean
    [effect_sizes23.xlsx]
2023-05-06 cleaning old hardware, new Mad_Edge to replace them
    [70553-0001.stp, Connections.sch, DesignProject.kicad_sch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]
2023-06-06 new Mad Edge being manufactured
    [MaD_Edge.kicad_pcb, MaD_Edge.kicad_sch, MaD_Edge_Sheet2.kicad_sch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]
2023-07-07 working version for getting basic data for the thesis
    [DS2_Addon.sch, MaD_Edge.kicad_pcb, MaD_Edge.kicad_sch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]
2023-07-19 issues with loading profiles, might be due to connector. last commit might be more stable
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2023-07-25 cleaning up production files
    [DS2_Addon-B_Cu.gbr, DS2_Addon-B_Mask.gbr, DS2_Addon-B_Paste.gbr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]
2023-08-08 Saving before end of work day
    [test_data.csv]
2023-08-11 uploading profiles and viewing is working
    [test_data copy.csv, test_data.csv]
2023-08-15 hot swappable sd card and headers for tests
    [test_data.csv]
2023-08-15 moving website to submodule
    [test_data copy.csv, test_data.csv]
2023-08-15 moving mad edge to submodule
    [MaD_Edge.kicad_pcb, MaD_Edge.kicad_sch, MaD_Edge_Sheet2.kicad_sch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]
2023-08-15 moving ds2 addon to submodule
    [DS2_Addon.kicad_pcb, DS2_Addon.sch]
2023-08-15 moving power board to submodule
    [Power-B_Cu.gbr, Power-B_Mask.gbr, Power-B_Paste.gbr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]
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
